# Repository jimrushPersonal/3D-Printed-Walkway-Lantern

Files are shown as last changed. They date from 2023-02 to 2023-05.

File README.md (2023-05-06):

# Smart-Walkway-Lantern
## Still a work in progress...

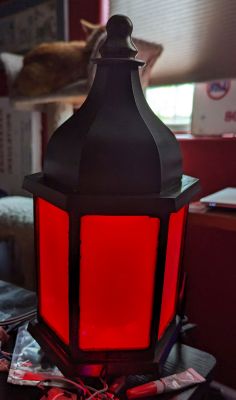
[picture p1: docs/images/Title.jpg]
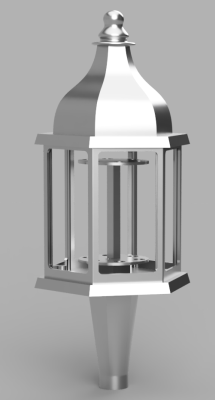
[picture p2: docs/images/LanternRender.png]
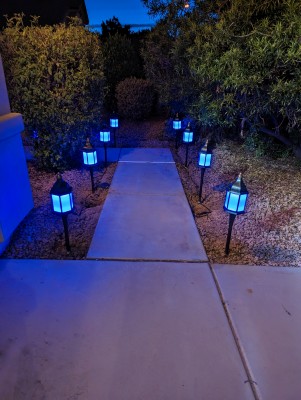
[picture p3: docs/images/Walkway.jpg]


## Project Introduction

This project was designed to accomplish two goals. First, I wanted to learn how to build more complicated things in Fusion 360.  Second, I wanted some cool, smart walkway lights for my house. This project contains the result of that exercise.

The walkway lights are roughly 12 inches tall, not counting the support stem. They are designed to be mounted on 3/4" PVC pipe.  Inside of each light is 12 outdoor Neopixel LEDs arranged with 6 towards the top and 6 towards the bottom. The controller is a ESP32 with a standard WLED image. I printed them in PETG, and will find out how they handle the Arizona summer in a few months.

### Disclaimer

This project was designed for me.  Not to be a solution for anybody out there with a 3D printer.  It is far from perfect and I don't consider this a ready to go project for anybody that wants to pick it up.  It might work for you, it might not. And, it hasn't been road tested outside of my own development environment.  You've been warned. 

### What is included

- Materials I used and links to anything I bought online (not affiliate links)
- Fusion 360 project
- STEP files exported from Fusion 360
- Prusa 3D generated .3mf files
- Some build progress pictures
- Commentary about each of the components

To avoid having a wall of text, I've broken this documentation into numerous parts to make it easier to digest. I listed the components from the bottom to the top.

If you get value, let me know: [eMail author](mailto:me@jimrush.net).

Jim Rush

## Table of Contents

- [Material List](/docs/CommonMaterials.md)
- [Post](/docs/Post.md)
- [Base](/docs/Base.md)
- [Light Stem](/docs/LightStem.md)
- [Body](/docs/Body.md)
- [Top](/docs/Top.md)
- [Tower and Finial](/docs/TowerAndFinial.md)
- [Electronics](/docs/Electronics.md)
- [Software](/docs/Software.md)

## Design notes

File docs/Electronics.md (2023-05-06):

# Electronics

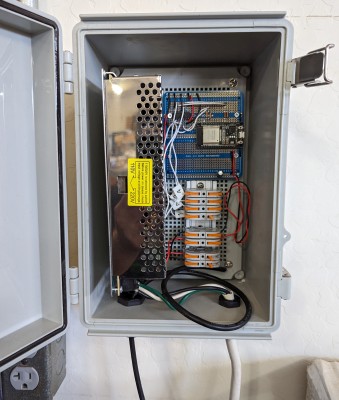
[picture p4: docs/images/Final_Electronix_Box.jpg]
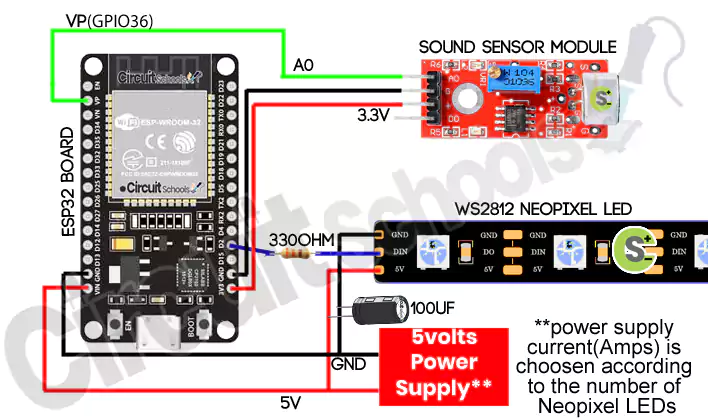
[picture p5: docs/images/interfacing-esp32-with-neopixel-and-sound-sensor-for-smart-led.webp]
 

There was limited creativity in the electronics. I followed a standard [WLED](https://kno.wled.ge/) deployment on an ESP32 board. The main difference in the diagram, above, was the inclusion of [SN74AHCT125N buffer gates](https://www.amazon.com/gp/product/B08R6BCSYC) to help protect the ESP32 from whatever may happen on the LED data lines. The other change, is the direct connection of the 5V supply to the LED line and not driving it off the ESP32 board.

Note, I did not attach a sound sensor module. I may create a [Nanoleaf](https://nanoleaf.me/en-US/) style project in the future. If so, I will probably add a sound sensor module to that implementation, but it didn't make sense for this project as I will not be playing audio to my neighbors.

The SN74AHCT125N package supports 4 buffers, so I wired up 4 data lines from the ESP32 for future lighting expansion. For example, some type of animated holiday display, or maybe even a sign display for in the workshop.  The [power supply](https://www.amazon.com/gp/product/B078RYWZMH/) is also oversized to support future lighting.

The project is packaged inside [water proof junction box](https://www.amazon.com/gp/product/B0B87VGV62). Given the environment and risks with lots of things happening in the outside world, I didn't want any issues reasonably contained. Most of the components in there should fail with only emitting some smoke.

The board shown is my second attempt. While testing one of the lanterns, I ended up letting smoke out of the ESP32 power circuit when something shorted. The original PCB didn't have any connecting traces so they wiring was a lot messier. The [new PCB](https://www.amazon.com/gp/product/B07YSCGBL7/) is a lot cleaner.

The circuit board, power supply and wiring are separated by a wiring panel to make the wiring a bit easier. The wiring panel is a [DIN rail](https://www.amazon.com/gp/product/B01JH2RZWC) with 8 [DIN terminal blocks](https://www.amazon.com/gp/product/B08R3FZ3QD).

On the other side of the wall from the project box is my patio entryway. I drilled a hole through the wall and just ran the wire, glueing it to the foundation pad to keep it less visible until it could go underground. Once I have more projects that use the LED controller, I'll come back and install some type of plug panel, so that various outdoor lighting projects can be plugged in. But, I think I need to know more about the future before it makes sense to pick a specific format.

As for the lantern wiring, the LED data lines are in series, from the first LED to the last. The power lines, however, are linked, lantern to lantern. Each 12 LED set is powered in series, but in parallel to the other lanterns. There was still a significant drop in voltage for the light levels to be notably different between the first and last lantern, which were right across the sidewalk from each other. I expected this and trenched out a path under the house side of the sidewalk path and connected the power and ground lines between the first and last lantern. This significantly smoothed out the brightness difference. I'm sure it gets dimmer as you go towards the drive way, but it isn't overly noticeably.

**Areas for improvement**
Other than the smoke failure, I didn't have any significant things I would do differently. I do want to learn how to draw and then make my own circuit boards (e.g. KiCad), but that was out of scope for this project.

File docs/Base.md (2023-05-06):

# Base

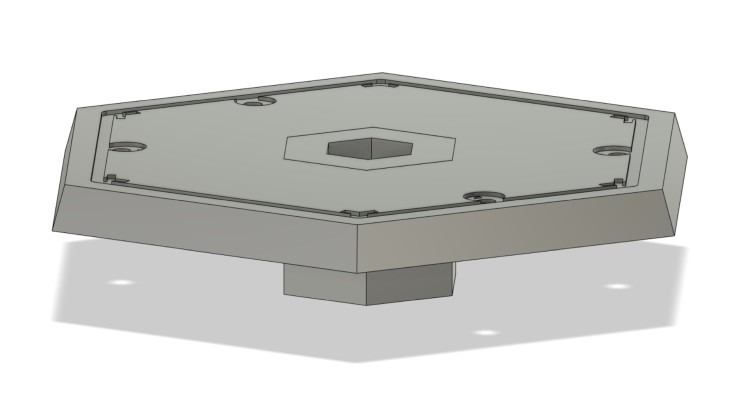
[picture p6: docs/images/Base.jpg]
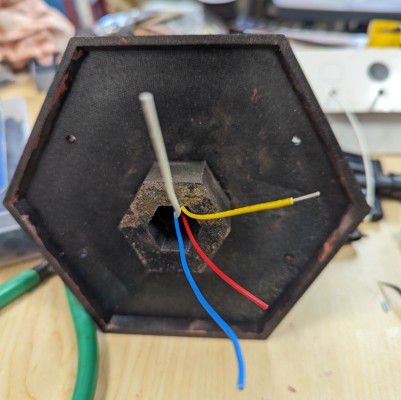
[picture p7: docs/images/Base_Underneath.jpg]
 

This is the base portion of the lantern. It was designed after building the main body. It has grooves to fit the body and attaches via screws.

Note, the top portion of this component (inside of lantern), is painted bright white to help reflect and diffuse the LED lighting.

**Areas for improvement**
- I should have made deeper grooves and maybe a slightly larger tollerance in the groove. this was a general problem with grooves. For the base, it was less of an issue as the screws locked the main body in place.

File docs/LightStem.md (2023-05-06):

# Light Stem

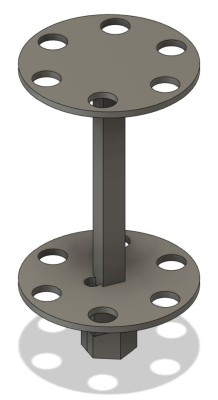
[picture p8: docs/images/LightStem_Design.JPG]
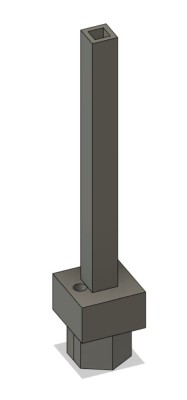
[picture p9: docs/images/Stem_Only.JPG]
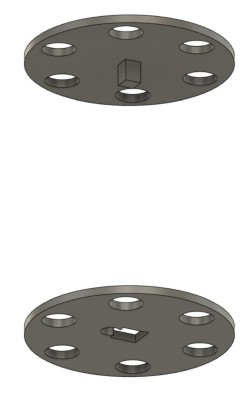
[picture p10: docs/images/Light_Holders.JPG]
  
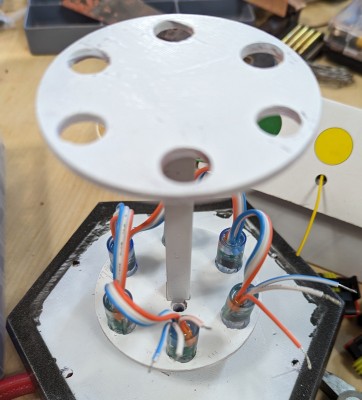
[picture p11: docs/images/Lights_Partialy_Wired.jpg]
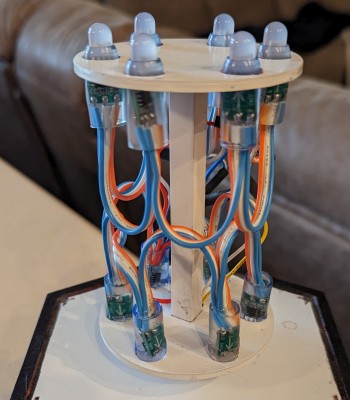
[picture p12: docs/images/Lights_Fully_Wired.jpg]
  

I'm reasonably happy with the light stem. I needed the LEDs to be high and low enough that they weren't that visible through the mylar, but far enough from the top and bottom to get a good spread of light. The current size is a reasonable compromise.  Anything better on that point would probably require significant design change.

The LED holes are sized close enough to the NEO Pixel size that just putting the LEDs into the hole with some force and using friction to keep them in place has worked well. Additionally, I've already had one LED fail on me and getting access to the LED to cut it out and replace it, worked reasonably well.

The base of the step has a hole for wiring to go down to the base.

The [NEO Pixel LEDs](https://www.amazon.com/gp/product/B01AG923GI) come in runs of 50. I cut them into runs of 6. The soldered the wires and sealed with [heat shrink tubing](https://www.amazon.com/gp/product/B0B38PGS1Y/).

**Areas for improvement**
- The link between the step and the top light holder is too weak. I broke one or two during assembly. Instead of the top feeding into the stop, it should have wrapped over it.
- The hole was just large enough. I think, a bigger hole would have been better as it would have allowed me to pull the wire joints into that space.

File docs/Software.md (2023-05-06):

# Software

<video width="640" height="480" controls>
  <source src="docs/images/LanternAnimation.mp4" type="video/mp4">
</video>

WLED is sufficient to drive the LEDs, but I really want animations that were aware of the lantern structure. For example, blinking runway style lights that could fly towards or away from the house. I also wanted to see if I could get a lantern flicker that I liked. There are only 12 LEDs, so that may be difficult.

The software is still in progress and will be tightly couple with my existing home automation software that is mostly home grown (e.g. Not Home Assistant or any other standard package). But, the animation logic should be reasonably decoupled. Once I can get it working, I might post the code. Anybody that uses it will need do some significant development to incorporate it in their own project.

**Areas for improvement**
TBD

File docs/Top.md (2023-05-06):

# Top

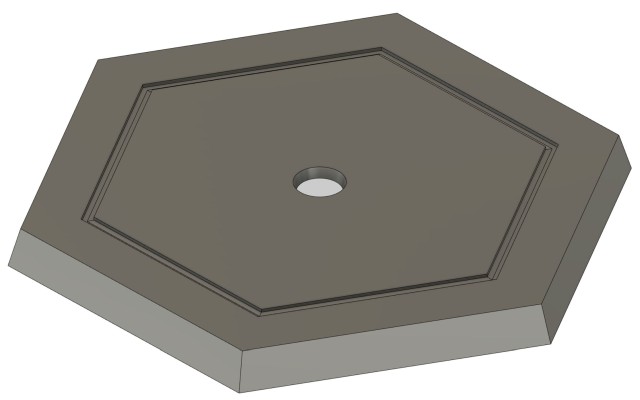
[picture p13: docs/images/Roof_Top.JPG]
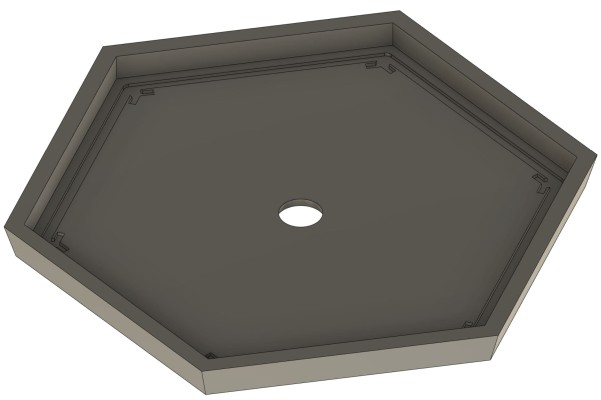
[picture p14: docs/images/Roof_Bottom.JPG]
 

The roof is a fairly simple design and is mostly an artifact of the body and the tower. Given that the tower and finial are glued together and then to the top, which could form a seal, I added a small hole for air or anything else that might get insight.

The underneath, inside of the lantern, is painted a bright white to reflect and defuse the LED lighting.

**Areas for improvement**
- Similar to the base, the grooves for the body and tower should have been larger. Given this is a glued joint, it would have helped with lining up the parts and I think improve adhesion. Note, that would have meant a thicker component, but I don't see that as a concern.
- While Fusion makes it easy to use the same sketch for the groove cuts, at the corners I would have preferred no guide or something with significantly larger tolerances.

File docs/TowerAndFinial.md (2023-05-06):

# Tower and Finial

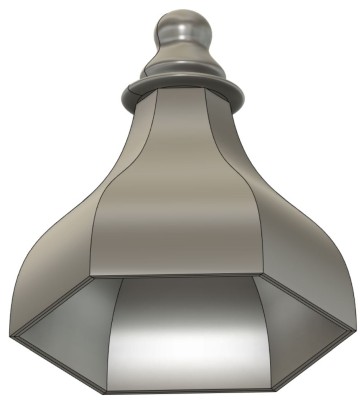
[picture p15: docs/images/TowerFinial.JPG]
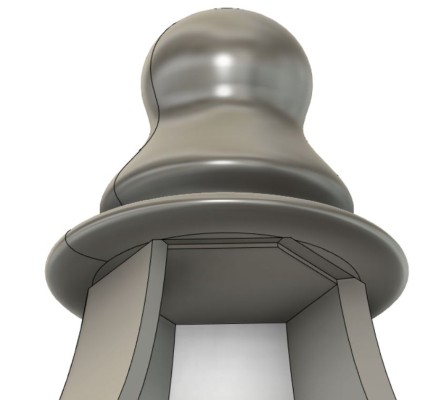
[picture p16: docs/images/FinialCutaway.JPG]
 

The tower and finial are both designed from swept splines. In general, I'm fairly happy with the results. 

The finial was sprayed with an antique bronze spray paint, which gave it a nice highlight on the lamp.

The finial is glued to the tower, which in turn is glued to the top.

**Areas for improvement**
- I had several issues with Fusion 360 around the tower. Mostly driven by my Fusion 360 experience. Several times I ended up with parts that were no longer tied to the their constraints as I tried different approaches.
- Similar to other parts in this project the part mating grooves needed to be much deeper and with larger tolerances. The current solution work, but took more effort to get glued correctly.

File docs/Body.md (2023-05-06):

# Body

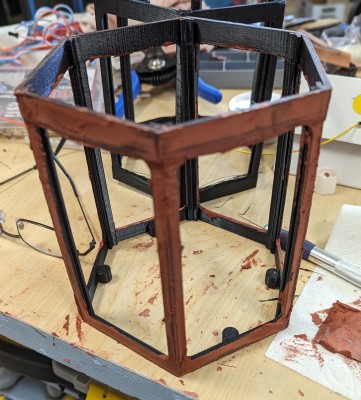
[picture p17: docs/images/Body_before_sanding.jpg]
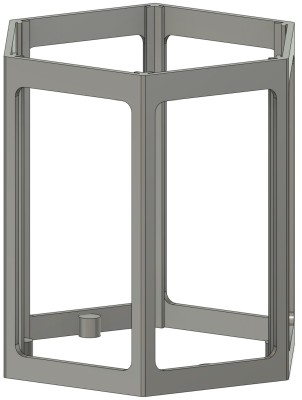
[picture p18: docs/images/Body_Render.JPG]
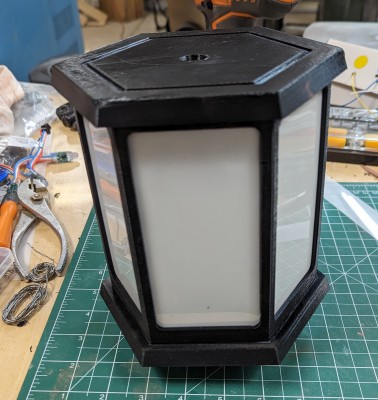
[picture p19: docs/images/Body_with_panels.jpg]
  

The body was the most complicated component and the one I am the most disappointed with. I would have liked to have allocated more time to it, but I put some limits on how much time I would spend and how many iterations.  Print time was significant, so it was difficult to include many of the lessons learned.

The body have several design iterations. My original plan was to support removable plastic covers in front of the mylar panels to allow for holiday themed shadow images.  I eventually discounted this while trying to get it to work and design images that I thought would look good at this scale. And, I realized it significantly grew the build.

Through experimentation, I decided two sheets of the mylar I purchased provided the best diffusion. I would still like more, but a third didn't improve it and started to detract from the lighting.

The mylar slides into slots on each side of the opening.  The bottom of the body has spots to embed [four nurled insert nuts](https://www.amazon.com/gp/product/B08G9NL291/ref=ppx_yo_dt_b_search_asin_title?ie=UTF8&psc=1) and connected to the base plate with [four m4 screws](https://www.amazon.com/gp/product/B08GH8LSGZ/ref=ppx_yo_dt_b_search_asin_title?ie=UTF8&th=1).

The body is glued to the top piece.  Both the Base and Top have groves to accept the body.

**Areas for improvement**
- In general, I think I might have been better off designing 6 sides that then attached to each other. Maybe with some type of pinned structure that then could be glued. It would have accelerated the prototyping significant, letting me address most of the problems below.
- I never found an upper bridge support I liked, so I ended not using one and just cleaning the print up
- The walls should have been thicker and support to prevent them from splaying. As the upper bridge reconnects posts, some shifting occurs. This caused the mylar slots to get bent. I had to force a putty knife down the slots to open and better align them. It isn't visible from the outside, but impacted the build.
- The top should have also been attached with screws. If the body or above is damaged, all pieces need to be reprinted. Additionally, it would have made it easier to replace the mylar sheets as the support for the insert nuts prevent the sheets from just being slid up when separated from the base.
- The post should have been thickened. Not so much for strength, but to provide better tolerances for the slots.

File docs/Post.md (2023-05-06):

# Post

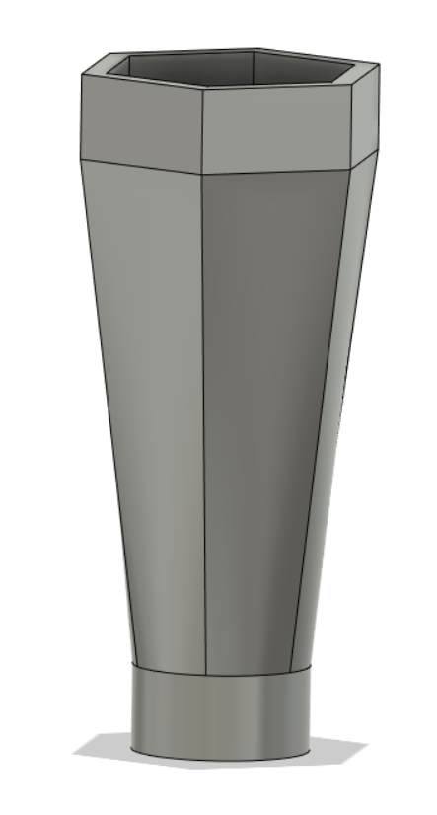
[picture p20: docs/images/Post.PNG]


I designed this component last. So, the result was an artifact of other decisions. In particular, I had already designed the bottom plate with a hex plug. I wanted the lanterns to be well supported so they wouldn't start leaning over, so I opted 1/2" rebar in a small amount of cement.  This was covered by a painted section of 3/4" 

This piece and the finial I filled by spraying the filler.

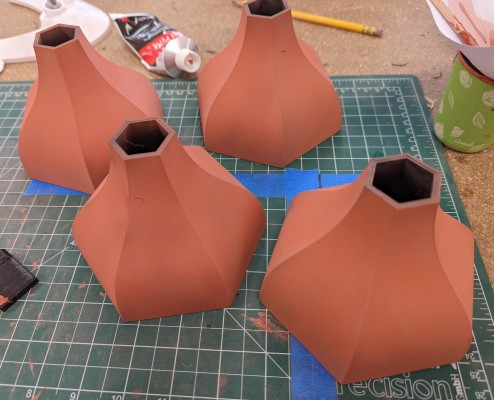
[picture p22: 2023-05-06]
docs/images/Tower_Post_Fill.jpg

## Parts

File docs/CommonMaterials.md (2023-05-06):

# Common Materials

## 3D Printing

I used a Prusa MK3+ printer for all printing along with the standard Prusa Slicer. There are some minor customizations in my print settings, but I don't think any of them are too important and were determined by this project.  Based on the slicer information, you could almost get 3 lanterns from a 1 Kg roll of filament. I had various printer failures, prototypes, ect. so I'm sure I used more.

* Filament: [OVERTURE PETG Filament 1.75mm](https://smile.amazon.com/gp/product/B0834428DQ)
* Bed adhesion [Elmer's Disappearing Purple School Glue Sticks](https://smile.amazon.com/gp/product/B00143SNPG)
* Bed cleaning [Denatured alcohol](https://www.homedepot.com/s/denatured%20alcohol%20gal)
* Body fill [3M Bondo 907 Glazing and Spot Putty](https://smile.amazon.com/dp/B07N6HFBRX?psc=1&ref=ppx_yo2ov_dt_b_product_details) - Note I use this for manual application as well as to spray on when diluted with Acetone.
* Sand paper, 220 grit
* Cement, Rebar and 3/4" PVC pipe to hold up the lanterns

## Electronics
* [ESP WROOM 32 ESP32](https://smile.amazon.com/gp/product/B09GK74F7N)
* [SN74AHCT125N SN74 Quadruple Bus Buffer Gate](https://smile.amazon.com/dp/B08R6BCSYC?psc=1&ref=ppx_yo2ov_dt_b_product_details)
* 100 uF capacitor
* Scrap board to hold electronics
* [5V 40A 200W Power Supply](https://smile.amazon.com/gp/product/B07KCVBZ18) This is significant overkill for the number of lanterns I have, but I will likely be adding other lighting displays powered by this setup
* [Project case](https://smile.amazon.com/gp/product/B0B87VGV62)
* [18 Gauge Electrical Wire 3 Conductor](https://smile.amazon.com/dp/B0B28M2C5Kref=ppx_yo2ov_dt_b_product_details)
* [Feed Thru Bushing](https://smile.amazon.com/gp/product/B07579PXVW)
* [Waterproof Wire Connectors](https://smile.amazon.com/dp/B0B4SG92LS) I would probably choose something smaller if I were to do it again. [Crimping tool for connectors](https://smile.amazon.com/dp/B071KFLY43)
* [WS2811 12mm Diffused Digital RGB LED Pixel Light](https://smile.amazon.com/dp/B01AG923GI)

## Paint

* White glossy spray paint - inner surfaces to reflect light
* Black metal spray paint - all out surfaces except the finial
* Bronze spray paint - the finial

## Other

* Fusion 360 Personal edition

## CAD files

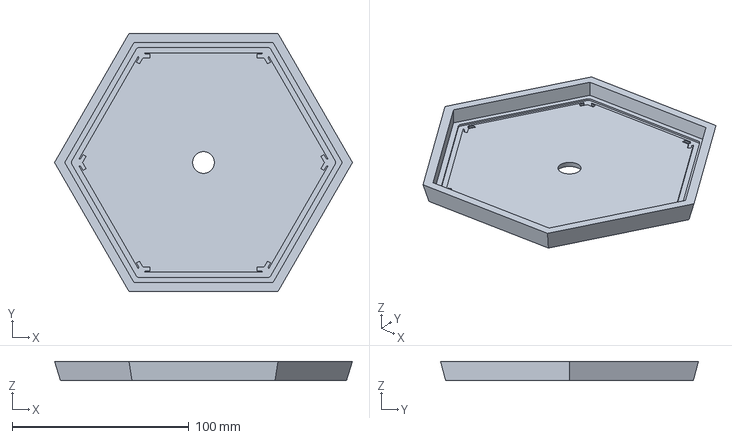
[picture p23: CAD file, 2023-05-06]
Models/RoofV2.3mf
168.6 x 146.0 x 11.0 mm

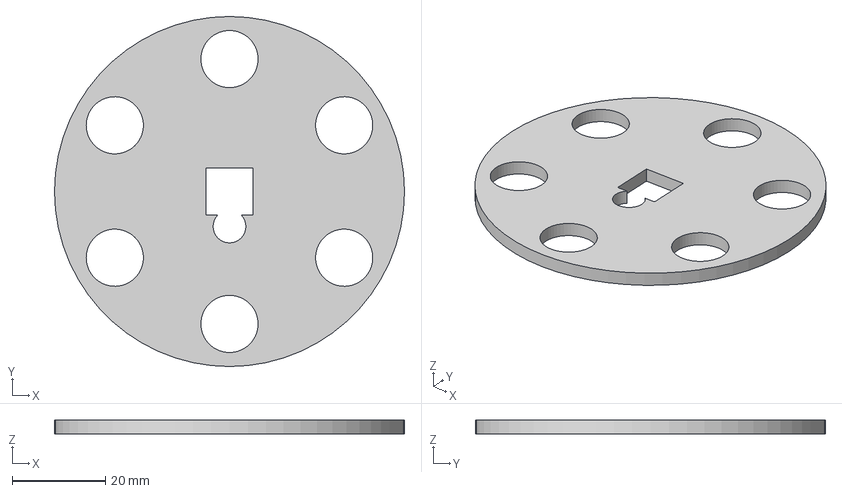
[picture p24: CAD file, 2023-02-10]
Models/LightHolder Bottom.step
75.0 x 75.0 x 3.00 mm

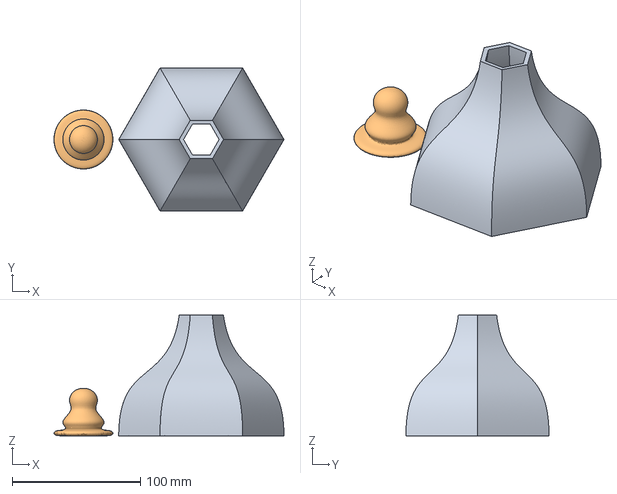
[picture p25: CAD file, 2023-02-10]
Models/Tower and Finial.3mf
179.6 x 111.8 x 94.1 mm
Tower
Finial

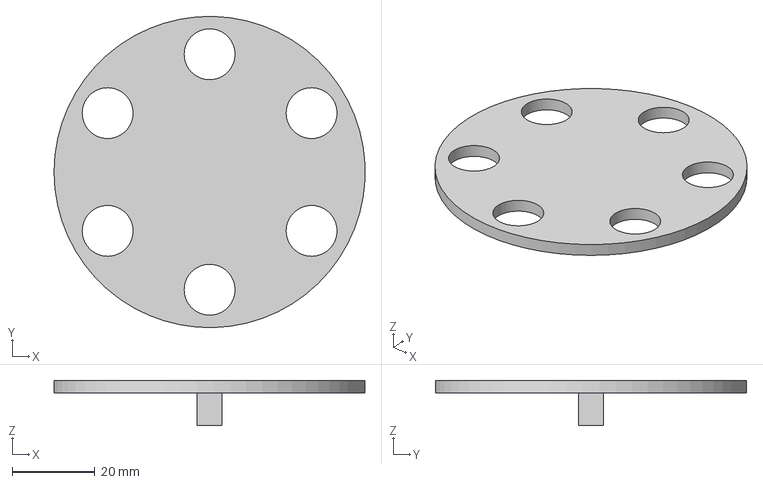
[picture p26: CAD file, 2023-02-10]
Models/LightHolder Top.step
74.9 x 75.0 x 10.9 mm

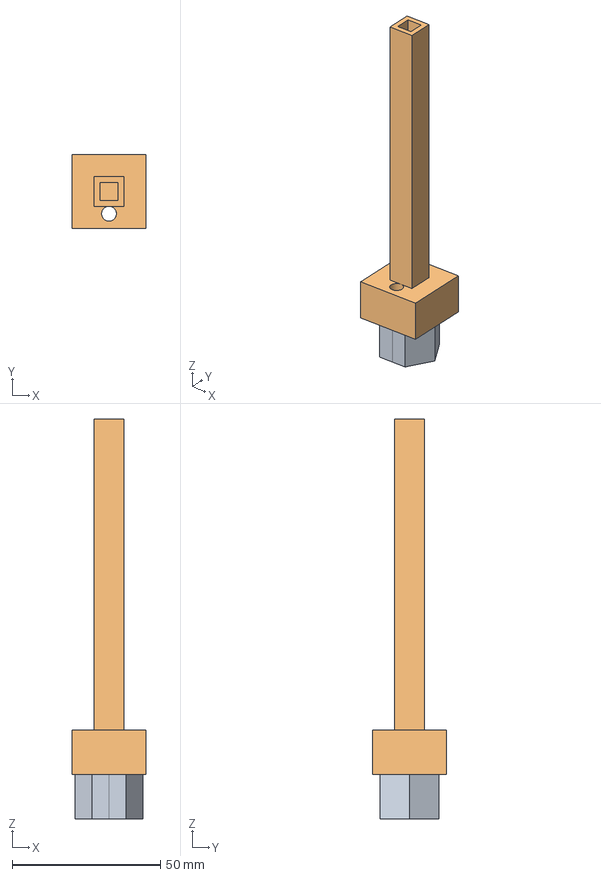
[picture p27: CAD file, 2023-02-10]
Models/LightStem.step
25.0 x 25.0 x 135.0 mm

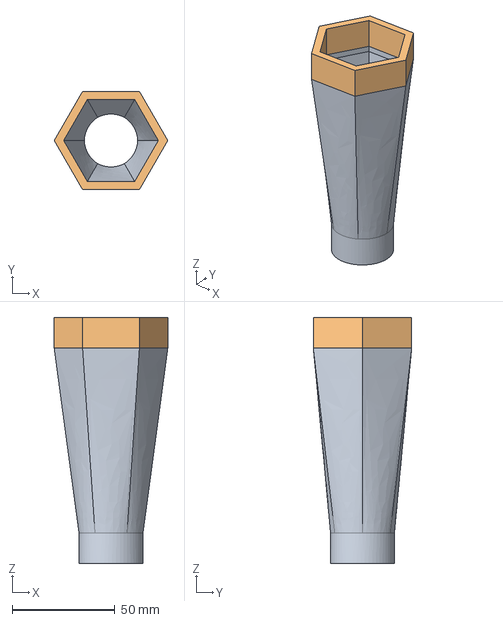
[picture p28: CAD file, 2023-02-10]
Models/Post.step
55.4 x 48.0 x 120.0 mm

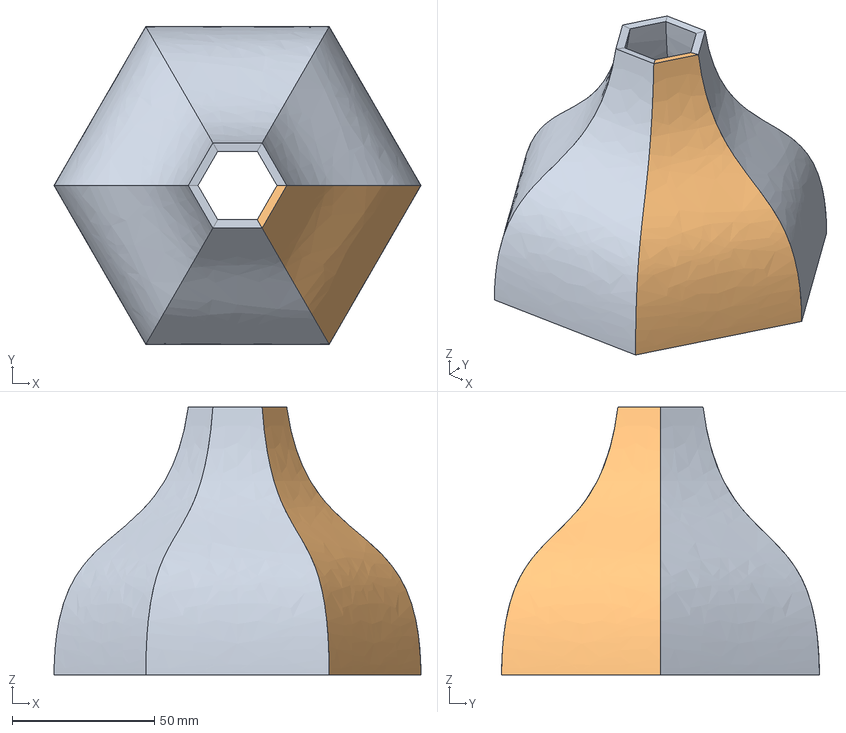
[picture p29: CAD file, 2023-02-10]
Models/Tower.step
129.1 x 111.8 x 94.1 mm

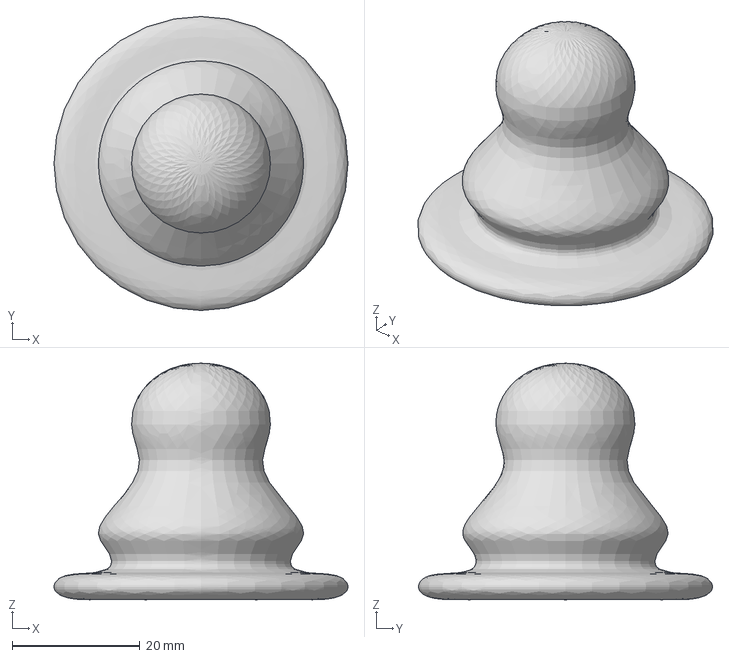
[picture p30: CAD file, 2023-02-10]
Models/Finial.step
46.0 x 46.0 x 37.0 mm

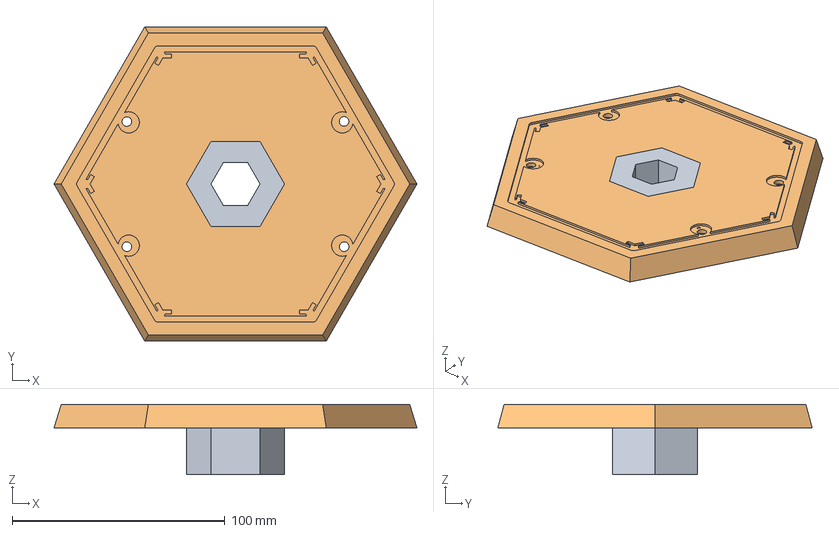
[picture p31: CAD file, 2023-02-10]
Models/BottomV2.step
170.8 x 147.9 x 33.0 mm

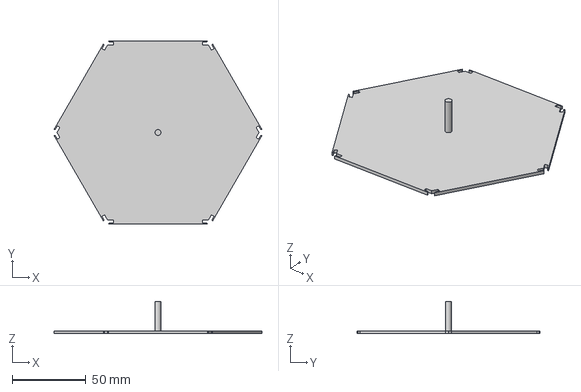
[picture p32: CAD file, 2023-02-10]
Models/PaintMask.step
140.9 x 124.0 x 22.0 mm

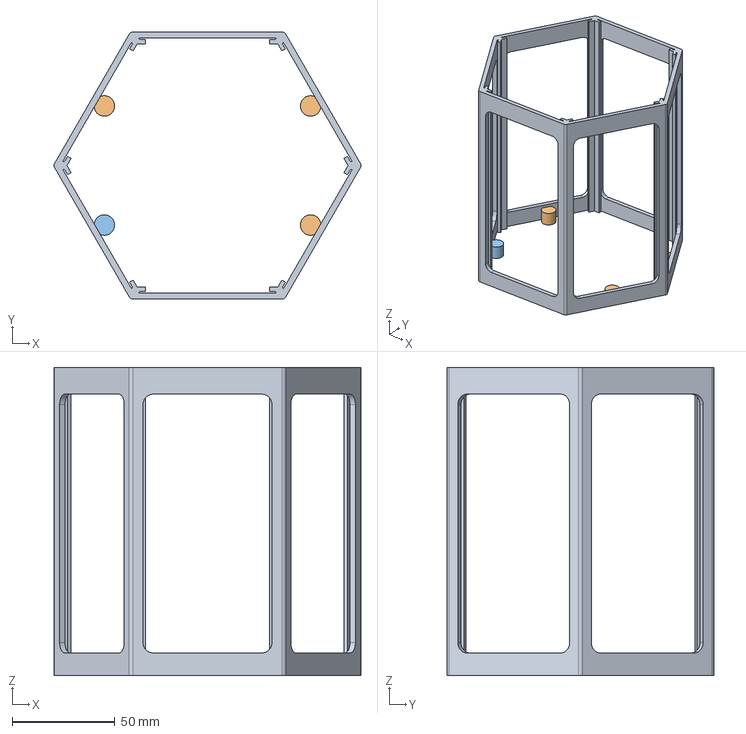
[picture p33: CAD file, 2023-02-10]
Models/BodyV2.step
149.5 x 130.0 x 150.0 mm
BodyV2 (1)
PanelCutout x 6

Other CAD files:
Models/BodyV2.3mf
Models/BottomV2.3mf
Models/LightStem.3mf
Models/PaintMask.3mf
Models/Post.3mf

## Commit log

2023-02-10 Created intro and removed body support prints that didn't work for me
    [BodyV2 with supports.3mf]
2023-05-06 Ongoing documentation update
    [BodyV2.3mf, BottomV2.3mf, LightStem.3mf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]
